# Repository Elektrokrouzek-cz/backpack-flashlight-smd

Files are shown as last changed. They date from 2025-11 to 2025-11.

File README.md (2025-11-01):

# Backpack flashlight - SMD
This is the construction of backpack flashlight with SMD components. It is based on ATTINY24A microcontroller.

PCB is 2-layer and was designed using KiCad 9. Fabrication output for JLCPCB is in gerber folder.

Happy soldering!

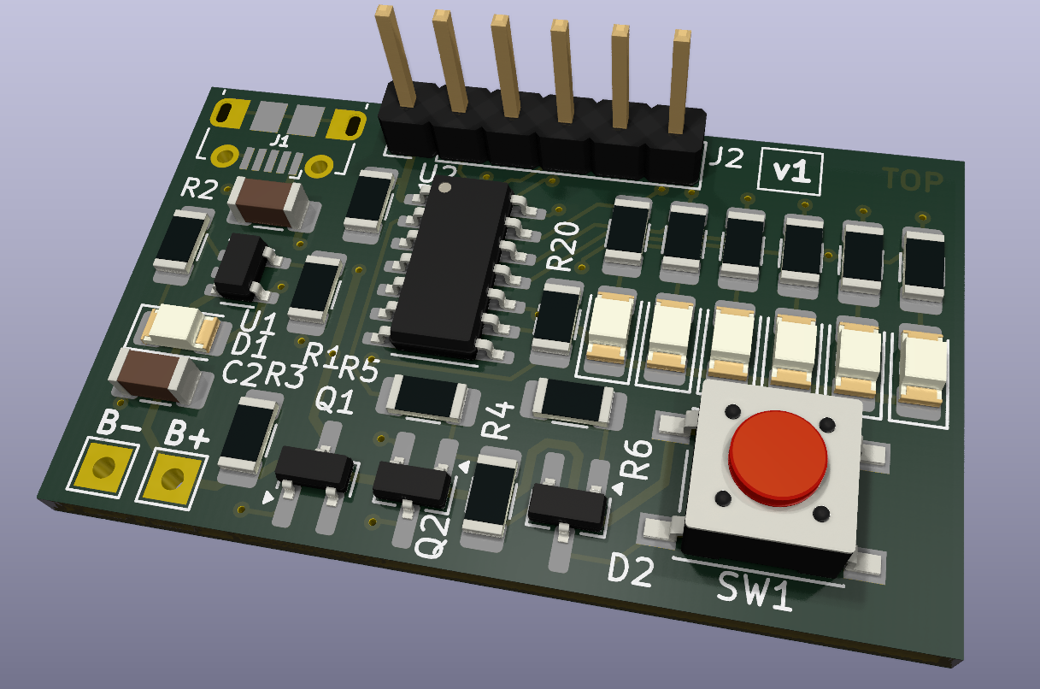
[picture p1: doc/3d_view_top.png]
3D view - top

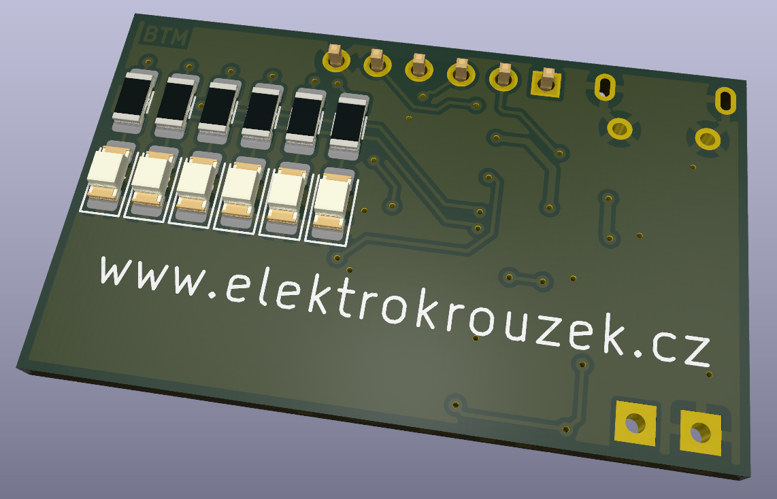
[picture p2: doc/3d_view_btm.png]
3D view - bottom

Flashlight

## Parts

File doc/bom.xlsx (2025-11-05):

Reference | Value | Qty
C1,C2 | 4u7 | 2
D1 | 1206 Red low intensity | 1
D3,D4,D5,D6,D7,D8,D9,D10,D11,D12,D13,D14 | 1206 Red high intensity | 12
D2 | BAS70-06 | 1
J1 | 105017-0001 | 1
J2 | 6pin | 1
Q1 | BSS84 | 1
Q2 | BC848 | 1
R1 | 47k | 1
R2 | 470R | 1
R3 | 2M2 | 1
R4,R5,R6,R19,R20 | 10k | 5
R7,R8,R9,R10,R11,R12,R13,R14,R15,R16,R17,R18 | 220R | 12
SW1 | 6x6 SMD | 1
TP1 | BAT+ | 1
TP2 | BAT- | 1
U1 | MCP73831-2-OT | 1
U2 | ATtiny24-20SS | 1

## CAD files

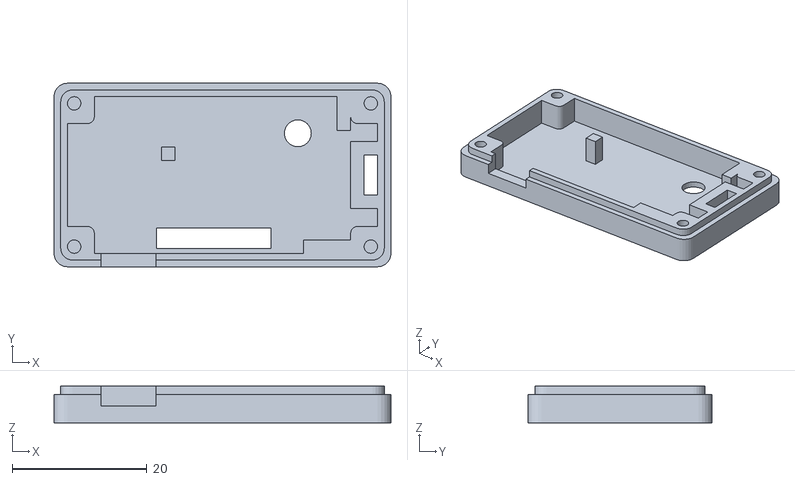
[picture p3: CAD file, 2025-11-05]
3d/Flashlight-top-hole.stl
50.1 x 27.3 x 5.50

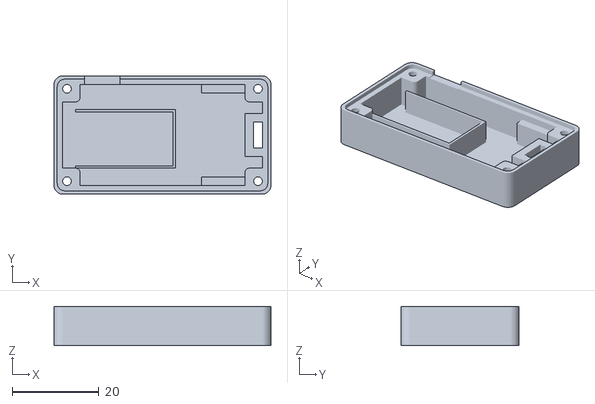
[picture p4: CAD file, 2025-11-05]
3d/Flashlight-bottom.stl
50.1 x 27.3 x 9.10

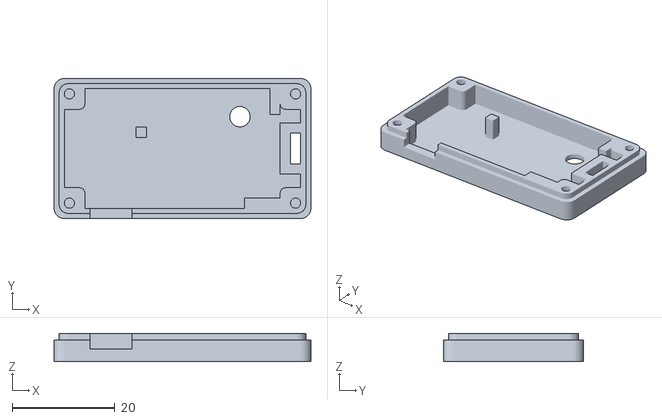
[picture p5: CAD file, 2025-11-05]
3d/Flashlight-top-no-hole.stl
50.1 x 27.3 x 5.50

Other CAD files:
3d/Flashlight-bottom.obj
3d/Flashlight-top-hole.obj
3d/Flashlight-top-no-hole.obj
3d/Flashlight.f3d

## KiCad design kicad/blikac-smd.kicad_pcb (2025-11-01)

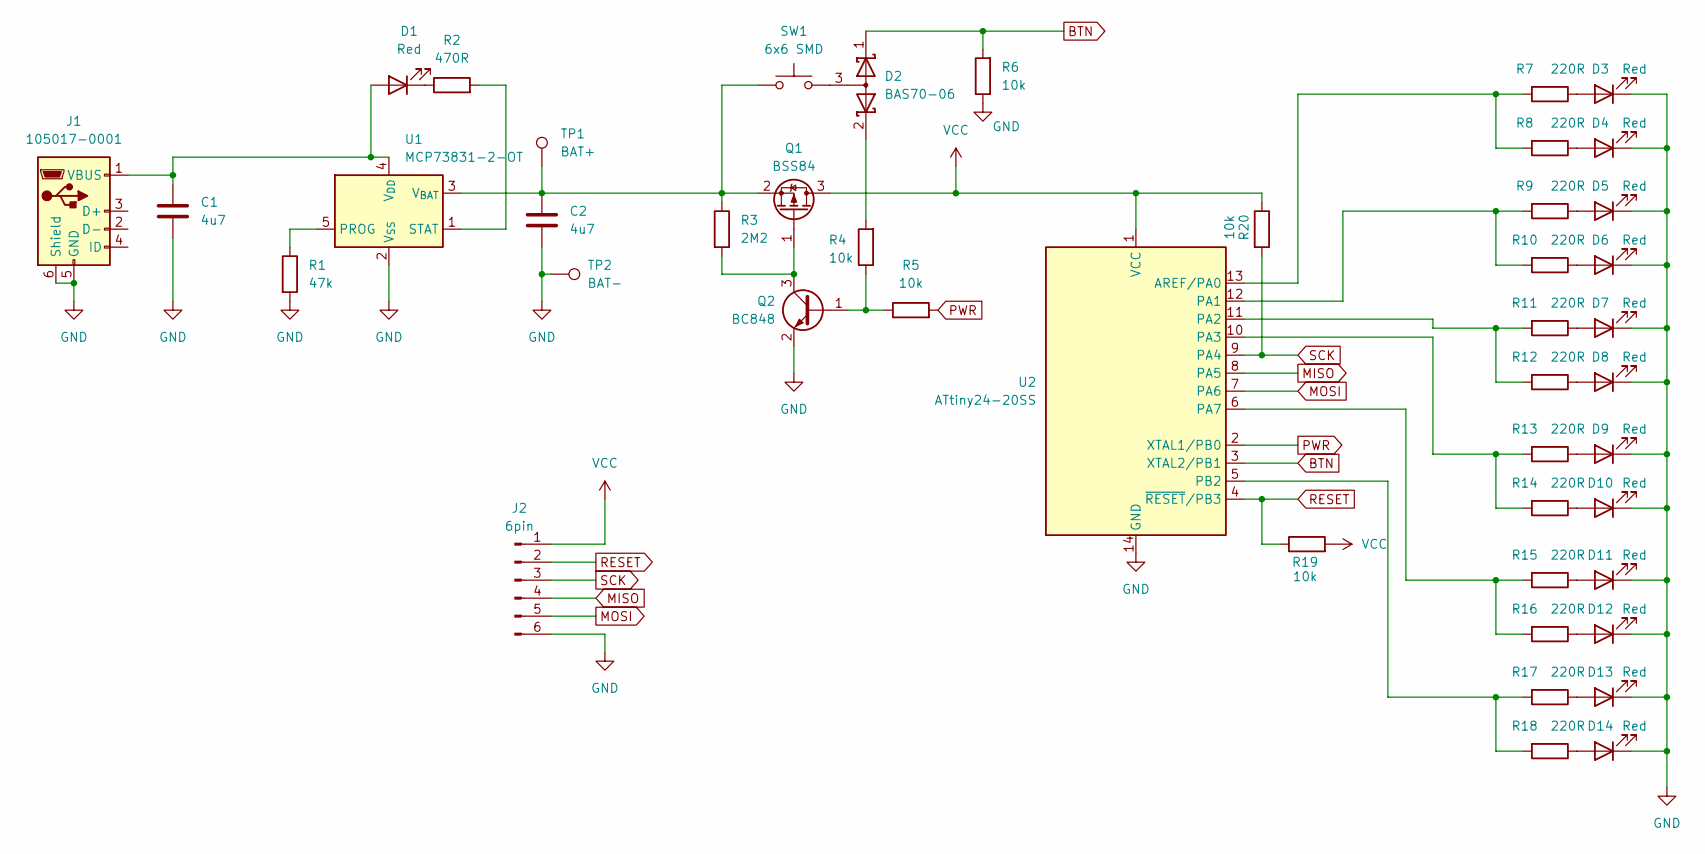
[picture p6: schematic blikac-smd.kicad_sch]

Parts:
C1, C2: 4u7; C_1206_3216Metric_Pad1.33x1.80mm_HandSolder
D1, D3, D4, D5, D6, D7, D8, D9, D10, D11, D12, D13, D14: Red; LED_1206_3216Metric_Pad1.42x1.75mm_HandSolder
D2: BAS70-06; SOT-23_Handsoldering
J1: 105017-0001; USB_Micro-B_Molex-105017-0001
J2: 6pin; PinHeader_1x06_P2.54mm_Vertical
Q1: BSS84; SOT-23_Handsoldering
Q2: BC848; SOT-23_Handsoldering
R1: 47k; R_1206_3216Metric_Pad1.30x1.75mm_HandSolder
R2: 470R; R_1206_3216Metric_Pad1.30x1.75mm_HandSolder
R3: 2M2; R_1206_3216Metric_Pad1.30x1.75mm_HandSolder
R4, R5, R6, R19, R20: 10k; R_1206_3216Metric_Pad1.30x1.75mm_HandSolder
R7, R8, R9, R10, R11, R12, R13, R14, R15, R16, R17, R18: 220R; R_1206_3216Metric_Pad1.30x1.75mm_HandSolder
SW1: 6x6 SMD; SW_SPST_PTS645
TP1: BAT+; TestPoint_THTPad_2.0x2.0mm_Drill1.0mm
TP2: BAT-; TestPoint_THTPad_2.0x2.0mm_Drill1.0mm
U1: MCP73831-2-OT; SOT-23-5
U2: ATtiny24-20SS; SOIC-14_3.9x8.7mm_P1.27mm

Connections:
BTN: D2.1 (K), R6.2, U2.3 (XTAL2/PB1)
GND: C1.2, C2.2, D3.1 (K), D4.1 (K), D5.1 (K), D6.1 (K), D7.1 (K), D8.1 (K), D9.1 (K), D10.1 (K), D11.1 (K), D12.1 (K), D13.1 (K), D14.1 (K), J1.5 (GND), J1.6 (Shield), J2.6, Q2.2 (E), R1.2, R6.1, TP2.1, U1.2 (V_{SS}), U2.14 (GND)
MISO: J2.4, U2.8 (PA5)
MOSI: J2.5, U2.7 (PA6)
unnamed: C1.1, D1.2 (A), J1.1 (VBUS), U1.4 (V_{DD})
unnamed: D1.1 (K), R2.1
unnamed: D2.3 (A), SW1.2
unnamed: D2.2 (K), R4.2
unnamed: D3.2 (A), R7.1
unnamed: D4.2 (A), R8.1
unnamed: D5.2 (A), R9.1
unnamed: D6.2 (A), R10.1
unnamed: D7.2 (A), R11.1
unnamed: D8.2 (A), R12.1
unnamed: D9.2 (A), R13.1
unnamed: D10.2 (A), R14.1
unnamed: D11.2 (A), R15.1
unnamed: D12.2 (A), R16.1
unnamed: D13.2 (A), R17.1
unnamed: D14.2 (A), R18.1
unnamed: Q1.1 (G), Q2.3 (C), R3.2
unnamed: C2.1, Q1.2 (S), R3.1, SW1.1, TP1.1, U1.3 (V_{BAT})
unnamed: Q2.1 (B), R4.1, R5.1
unnamed: R1.1, U1.5 (PROG)
unnamed: R2.2, U1.1 (STAT)
unnamed: R7.2, R8.2, U2.13 (AREF/PA0)
unnamed: R9.2, R10.2, U2.12 (PA1)
unnamed: R11.2, R12.2, U2.11 (PA2)
unnamed: R13.2, R14.2, U2.10 (PA3)
unnamed: R15.2, R16.2, U2.6 (PA7)
unnamed: R17.2, R18.2, U2.5 (PB2)
PWR: R5.2, U2.2 (XTAL1/PB0)
RESET: J2.2, R19.1, U2.4 (~RESET/PB3)
SCK: J2.3, R20.2, U2.9 (PA4)
VCC: J2.1, Q1.3 (D), R19.2, R20.1, U2.1 (VCC)

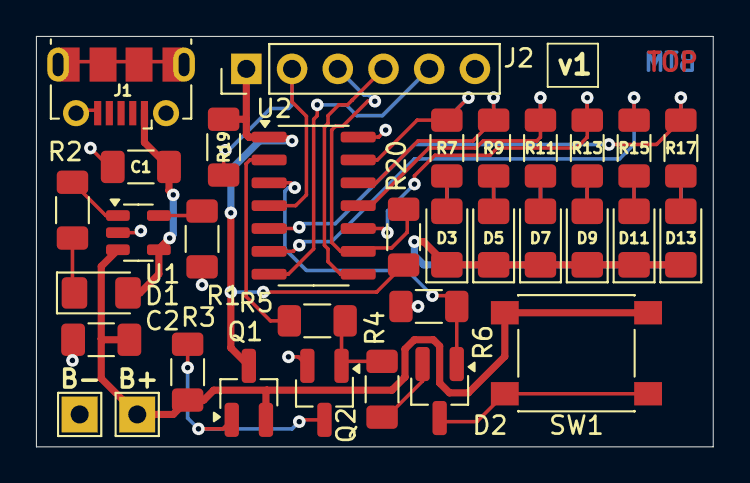
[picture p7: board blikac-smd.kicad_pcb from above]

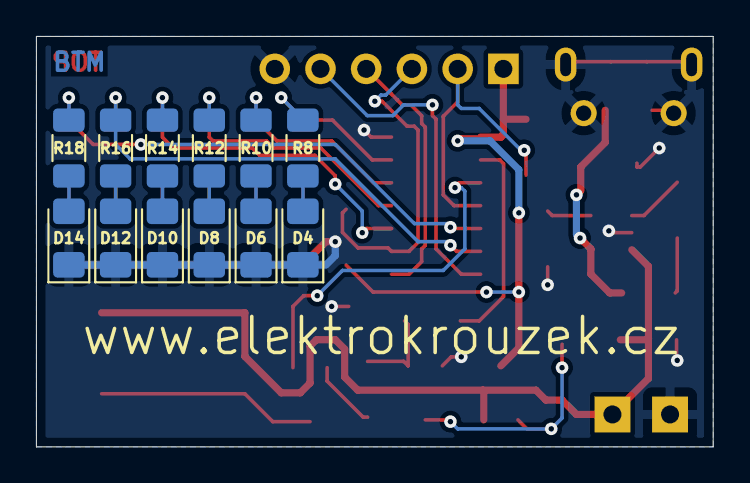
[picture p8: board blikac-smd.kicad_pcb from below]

Board: 2 copper layers, 37.6 x 22.8 mm, 45 parts (12 on the bottom side), 35 nets.

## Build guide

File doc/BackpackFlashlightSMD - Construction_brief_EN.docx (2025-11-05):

# Backpack Flashlight SMD

## Bill of materials

Annotation | Value | Qty
C1,C2 | 4u7 | 2
D1 | 1206 Red low intensity | 1
D3,D4,D5,D6,D7,D8,D9,D10,D11,D12,D13,D14 | 1206 Red high intensity | 12
D2 | BAS70-06 | 1
J1 | 105017-0001 | 1
J2 | 6pin | 1
Q1 | BSS84 | 1
Q2 | BC848 | 1
R1 | 47k | 1
R2 | 470R | 1
R3 | 2M2 | 1
R4,R5,R6,R19,R20 | 10k | 5
R7,R8,R9,R10,R11,R12,R13,R14,R15,R16,R17,R18 | 220R | 12
SW1 | 6x6 SMD | 1
TP1 | BAT+ | 1
TP2 | BAT- | 1
U1 | MCP73831-2-OT | 1
U2 | ATtiny24-20SS | 1

## PCB assembly

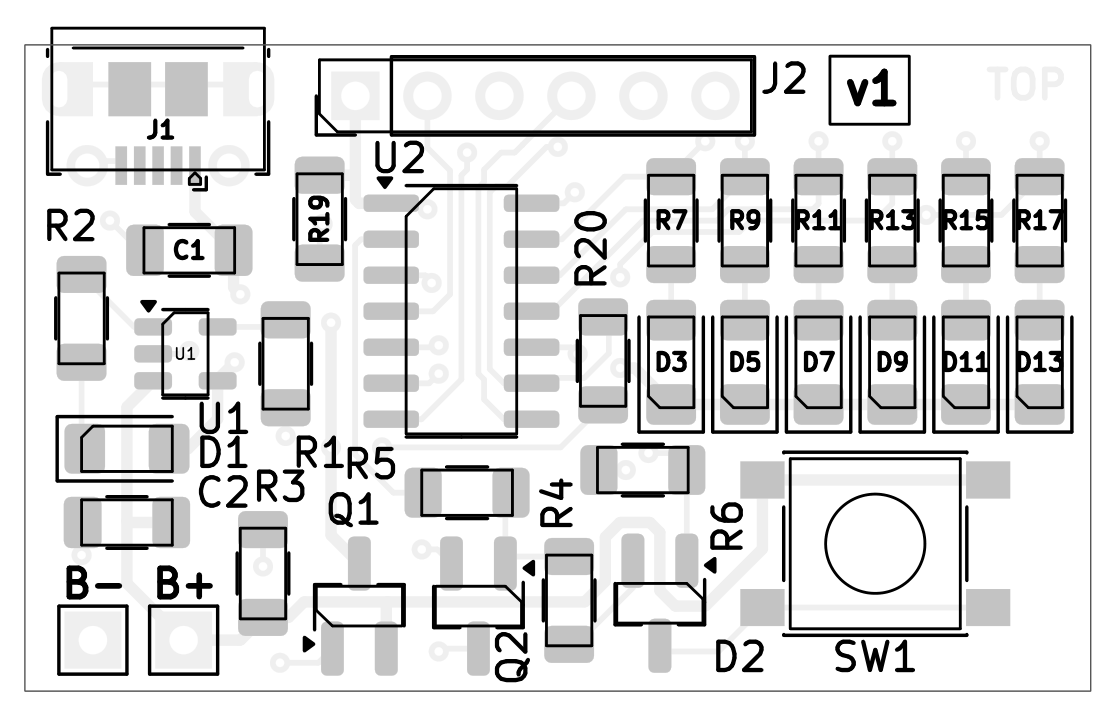
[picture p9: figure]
Obsah obrázku text, diagram, Plán, snímek obrazovky Obsah generovaný pomocí AI může být nesprávný.
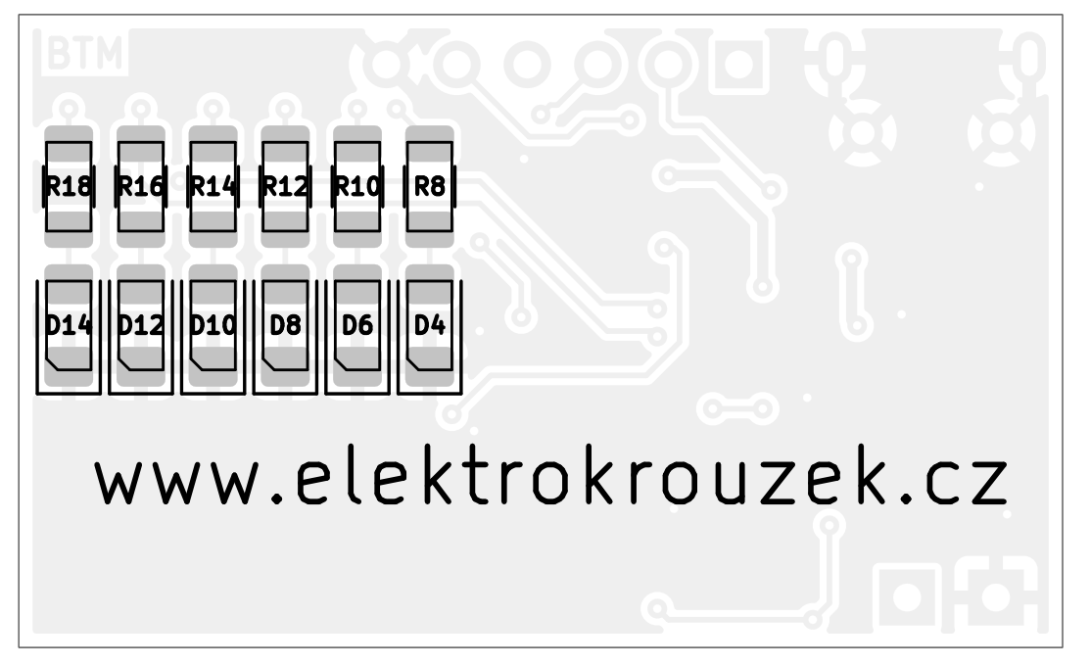
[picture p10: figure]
Obsah obrázku text, snímek obrazovky, Písmo, číslo Obsah generovaný pomocí AI může být nesprávný.

## Schematic

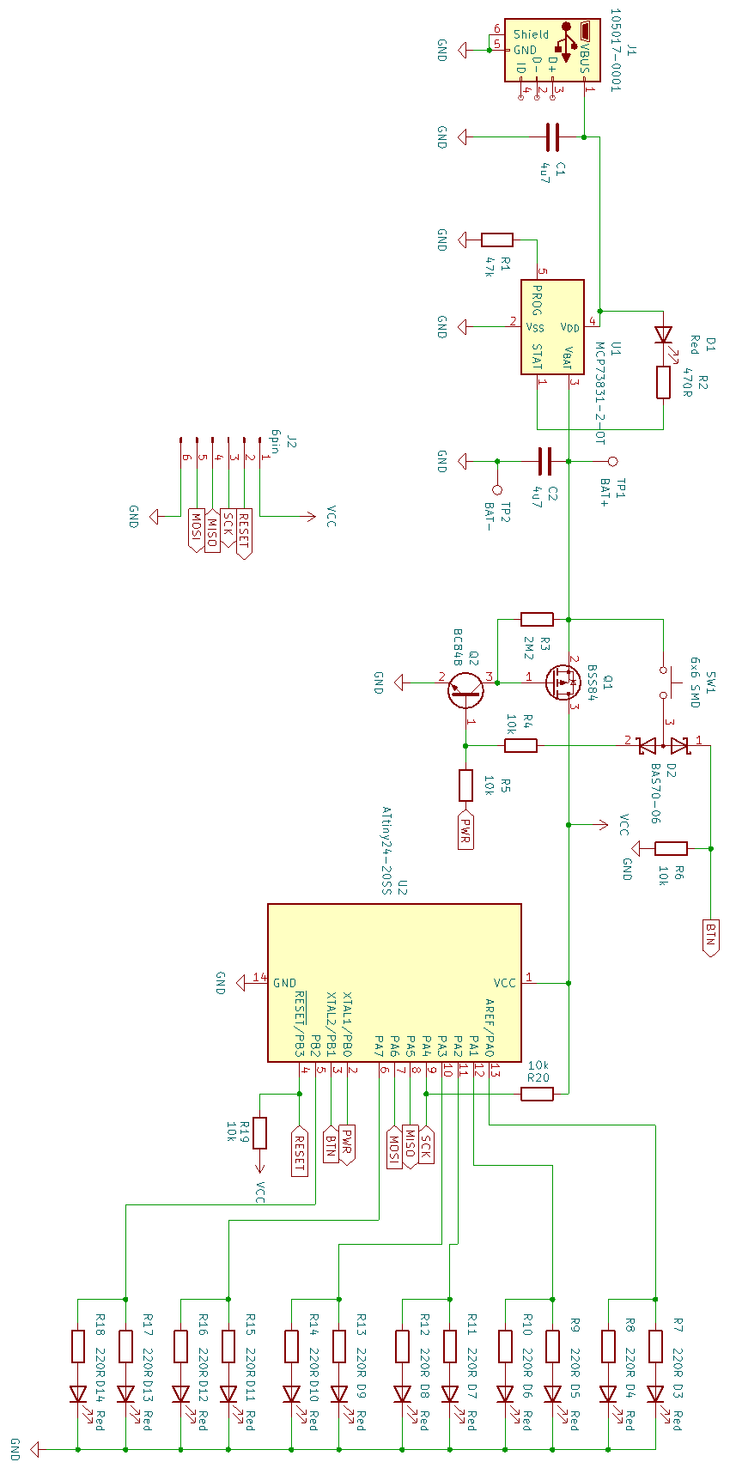
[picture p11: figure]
Obsah obrázku text, diagram, Plán Obsah generovaný pomocí AI může být nesprávný.

www.elektrokrouzek.cz

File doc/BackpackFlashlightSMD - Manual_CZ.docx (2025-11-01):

# Blikač na batoh SMD

## Popis zapojení

Konstrukce blikače na batoh založená na SMD komponentech.

Konstrukce je založena na mikrokontroleru ATTINY24A. Je napájena malým LiPol akumulátorem s nabíjecím obvodem. Obvod je zapnut držením tlačítka nejméně 2 sekundy. The circuit is turned on by holding a button for at least 2 seconds. Tranzistory Q2 a Q1 se otevřou ve chvíli stlačení tlačítka a dodávají napájecí napětí mikrokontroleru. Mikrokontroler následně aktivuje signál PWR, aby přidržel tranzistory otevřené i po uvolnění tlačítka. Stav tlačítka je signalizován signálem BTN, který je izolovaný od signálu PWR schottkyho diodou D2.

## Popis sestavení

Součástky jsou osazeny z obou stran plošného spoje. Začneme osazováním USB konektoru, rezistorů, kondenzátorů, diody D2, tranzistorů, mikrokontroleru a LED diod. Nakonec osadíme integrované obvody, tlačítko a připojíme akumulátor.

Poznámka: LED diody jsou v 1206 SMD pouzdru. Lze použít jakýkoliv typ. Nejlepší jsou LED diody s malým vyzařovacím úhlem.

## Oživení

Pokud jste pracovali pečlivě mělo by zapojení fungovat na první pokus, pokud je mikrokontroler naprogramován.

## Seznam součástek

Označení | Hodnota | Počet
C1,C2 | 4u7 | 2
D1,D3,D4,D5,D6,D7,D8,D9,D10,D11,D12,D13,D14 | 1206 Red | 13
D2 | BAS70-06 | 1
J1 | 105017-0001 | 1
J2 | 6pin | 1
Q1 | BSS84 | 1
Q2 | BC848 | 1
R1 | 47k | 1
R2 | 470R | 1
R3 | 2M2 | 1
R4,R5,R6,R19,R20 | 10k | 5
R7,R8,R9,R10,R11,R12,R13,R14,R15,R16,R17,R18 | 220R | 12
SW1 | 6x6 SMD | 1
TP1 | BAT+ | 1
TP2 | BAT- | 1
U1 | MCP73831-2-OT | 1
U2 | ATtiny24-20SS | 1

## Osazovací výkresy

Obsah obrázku text, diagram, Plán, snímek obrazovky Obsah generovaný pomocí AI může být nesprávný.
Obsah obrázku text, snímek obrazovky, Písmo, číslo Obsah generovaný pomocí AI může být nesprávný.

## Programování mikrokontroleru

K naprogramování mikrokontroleru lze použít nejrůznější programátory pro Atmer AVR. My jsme použili programátor Asix Presto. Následující obrázek znázorňuje propojení programátoru s konektorem J2 (čísla pinů konektoru J2 jsou červeně).

Zdrojový kód a binární soubor je ke stažení na githubu kroužku:

https://github.com/Elektrokrouzek-cz/backpack-flashlight-smd

## Schéma

Obsah obrázku text, diagram, Plán Obsah generovaný pomocí AI může být nesprávný.

www.elektrokrouzek.cz

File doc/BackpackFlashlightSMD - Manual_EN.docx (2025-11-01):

# Backpack Flashlight SMD

## Schematic description

This is a construction of backpack flashlight based on SMD components.

The whole construction is based on ATTINY24 microcontroller. It is powered by tiny LiPol accumulator with charging circuit. The circuit is turned on by holding a button for at least 2 seconds. Q2 and Q1 transistors are turned on when button is pressed sourcing microcontroller with power. Microcontroller then activates PWR signal to keep transistors turned on. Button state is signalized by BTN signal that is isolated from the PWR signal by dual Schottky diode D2.

## Construction

Construction has components placed on both sides of the PCB. We start populating USB connector, resistors, then continue with capacitors, diode D2, transistors and LEDs. Finally, we populated ICs and button.

Note: LED diodes are in 1206 SMD package. You can use any type. The best are LED diodes with low emitting angle.

## How to get it into service

It should work on the first try when everything is soldered well and microcontroller is programmed.

## Bill of materials

Annotation | Value | Qty
C1,C2 | 4u7 | 2
D1,D3,D4,D5,D6,D7,D8,D9,D10,D11,D12,D13,D14 | 1206 Red | 13
D2 | BAS70-06 | 1
J1 | 105017-0001 | 1
J2 | 6pin | 1
Q1 | BSS84 | 1
Q2 | BC848 | 1
R1 | 47k | 1
R2 | 470R | 1
R3 | 2M2 | 1
R4,R5,R6,R19,R20 | 10k | 5
R7,R8,R9,R10,R11,R12,R13,R14,R15,R16,R17,R18 | 220R | 12
SW1 | 6x6 SMD | 1
TP1 | BAT+ | 1
TP2 | BAT- | 1
U1 | MCP73831-2-OT | 1
U2 | ATtiny24-20SS | 1

## PCB assembly

Obsah obrázku text, diagram, Plán, snímek obrazovky Obsah generovaný pomocí AI může být nesprávný.
Obsah obrázku text, snímek obrazovky, Písmo, číslo Obsah generovaný pomocí AI může být nesprávný.

## Microcontroller programming

Several programmers for Atmel AVR can be used for microcontroller programming. We’ve used Asix Presto. Following picture shows connection of Asix Presto to J2 connector (J2 pin numbers are red).

Source code and binary file can be downloaded from club github:

https://github.com/Elektrokrouzek-cz/backpack-flashlight-smd

## Schematic

Obsah obrázku text, diagram, Plán Obsah generovaný pomocí AI může být nesprávný.

www.elektrokrouzek.cz

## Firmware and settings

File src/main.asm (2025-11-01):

start:
	ldi r16,low(RAMEND)			// Init stack pointer
	out SPL,r16
power_on_wait_button:
	ldi r16, 5					// Wait 50ms
	rcall sleep_10ms
	in r16, PINB
	andi r16, 0x02				// Check if button is still pressed
	breq power_on_wait_button
	inc r17						// Increment counter
	cpi r17, 40					// Holding button for 2 seconds?
	brge power_on				// Yes -> turn on
	rjmp power_on_wait_button
power_on:
	ldi r16, 0x05				// Init PORTB (outputs)
	out DDRB, r16
	ldi r16, 0x01				// Power on (turn on transistor)
	out PORTB, r16
	ldi r16, 0x8f				// Init PORTA (outputs)
	out DDRA, r16
	ldi r16, 0x0
	out PORTA, r16

	ldi r17, 0					// Selected program
	ldi r18, 0					// LED content
	ldi r19, 0					// Program step
	ldi r20, 0					// Button hold counter
	ldi r21, 0					// Wait for button release
loop:
	in r16, PINB
	andi r16, 0x02				// Check if button is pressed
	brne loop_inc_button		
	clr r20						// Button not pressed - reset timers
	clr r21
	rjmp loop_skip_button
loop_inc_button:
	inc r20						// Button pressed - increment hold timer
	cpi r20, 40					// Check if it is held for 2 seconds
	brlo loop_check_prog_change // No -> check for program change
	rjmp power_off				// Turn off
loop_check_prog_change:
	cpi r20, 2					// Check if held for 100ms
	brlo loop_skip_button		// No -> skip
	cpi r21, 1					// Wait for button release
	breq loop_skip_button		// Button not released -> skip
	ldi r21, 1					// Set "wait for button release" flag
	inc r17						// Increment program
	cpi r17, 6					// Check maximal program count
	brne loop_skip_button
	clr r17						// Set program 0

loop_skip_button:
	cpi r17, 0					// Program 0?
	brne loop_1
	rcall prog_1
loop_1:
	cpi r17, 1					// Program 1?
	brne loop_2
	rcall prog_2
loop_2:
	cpi r17, 2					// Program 2?
	brne loop_3
	rcall prog_3
loop_3:
	cpi r17, 3					// Program 3?
	brne loop_4
	rcall prog_4
loop_4:
	cpi r17, 4					// Program 4?
	brne loop_5
	rcall prog_5
loop_5:
	cpi r17, 5					// Program 5?
	brne loop_6
	rcall prog_6
loop_6:
	mov r16, r18				// Show LEDs
	rcall show
	ldi r16, 5					// Wait 50ms
	rcall sleep_10ms
	rjmp loop					// And again!

power_off:
	ldi r16, 0x21				// Display turn off LED sequence
	rcall show
	ldi r16, 50
	rcall sleep_10ms
	ldi r16, 0x12
	rcall show
	ldi r16, 50
	rcall sleep_10ms
	ldi r16, 0x0c
	rcall show
	ldi r16, 50
	rcall sleep_10ms
	ldi r16, 0x0
	rcall show
	ldi r16, 50
	rcall sleep_10ms
	clr r17
power_off_wait_button:
	ldi r16, 5					// Wait 50ms
	rcall sleep_10ms
	in r16, PINB
	andi r16, 0x02				// Check button release
	brne power_off_wait_button_reset // No -> reset counter
	inc r17
	cpi r17, 4					// Button must be released for 40ms
	brlo power_off_wait_button
power_off_loop:
	ldi r16, 0					// Turn off
	out PORTB, r16
	rjmp power_off_loop
power_off_wait_button_reset:
	clr r17						// Reset counter
	rjmp power_off_wait_button  // And wait again

// Program 1 - blink all LEDs
prog_1:
	cpi r19, 0
	brne prog_1_1
	ldi r18, 0
	rjmp prog_1_inc
prog_1_1:
	cpi r19, 5
	brne prog_1_2
	ldi r18, 0x3f
	rjmp prog_1_inc
prog_1_2:
prog_1_inc:
	inc r19
	cpi r19, 7
	brlo prog_1_end
	clr r19
prog_1_end:
	ret

// Program 2 - blink left, blink right
prog_2:
	cpi r19, 0
	brne prog_2_1
	ldi r18, 0
	rjmp prog_2_inc
prog_2_1:
	cpi r19, 3
	brne prog_2_2
	ldi r18, 0x07
	rjmp prog_2_inc
prog_2_2:
	cpi r19, 4
	brne prog_2_3
	ldi r18, 0
	rjmp prog_2_inc
prog_2_3:
	cpi r19, 5
	brne prog_2_4
	ldi r18, 0x07
	rjmp prog_2_inc
prog_2_4:
	cpi r19, 6
	brne prog_2_5
	ldi r18, 0
	rjmp prog_2_inc
prog_2_5:
	cpi r19, 9
	brne prog_2_6
	ldi r18, 0x38
	rjmp prog_2_inc
prog_2_6:
	cpi r19, 10
	brne prog_2_7
	ldi r18, 0
	rjmp prog_2_inc
prog_2_7:
	cpi r19, 11
	brne prog_2_8
	ldi r18, 0x38
	rjmp prog_2_inc
prog_2_8:
prog_2_inc:
	inc r19
	cpi r19, 12
	brlo prog_2_end
	clr r19
prog_2_end:
	ret

// Program 3 - knight rider
prog_3:
	mov r16, r19
	cpi r19, 6
	brge prog_3_1
	ldi r18, 1
prog_3_lsl:
	cpi r16, 0
	breq prog_3_inc
	lsl r18
	dec r16
	rjmp prog_3_lsl
prog_3_1:
	ldi r18, 0x20
	subi r16, 6
prog_3_lsr:
	cpi r16, 0
	breq prog_3_inc
	lsr r18
	dec r16
	rjmp prog_3_lsr
prog_3_2:
prog_3_inc:
	inc r19
	cpi r19, 12
	brlo prog_3_end
	clr r19
prog_3_end:
	ret

// Program 4 - blink center, blink outer
prog_4:
	cpi r19, 0
	brne prog_4_1
	ldi r18, 0
	rjmp prog_4_inc
prog_4_1:
	cpi r19, 3
	brne prog_4_2
	ldi r18, 0x0c
	rjmp prog_4_inc
prog_4_2:
	cpi r19, 4
	brne prog_4_3
	ldi r18, 0
	rjmp prog_4_inc
prog_4_3:
	cpi r19, 5
	brne prog_4_4
	ldi r18, 0x0c
	rjmp prog_4_inc
prog_4_4:
	cpi r19, 6
	brne prog_4_5
	ldi r18, 0
	rjmp prog_4_inc
prog_4_5:
	cpi r19, 9
	brne prog_4_6
	ldi r18, 0x33
	rjmp prog_4_inc
prog_4_6:
	cpi r19, 10
	brne prog_4_7
	ldi r18, 0
	rjmp prog_4_inc
prog_4_7:
	cpi r19, 11
	brne prog_4_8
	ldi r18, 0x33
	rjmp prog_4_inc
prog_4_8:
prog_4_inc:
	inc r19
	cpi r19, 12
	brlo prog_4_end
	clr r19
prog_4_end:
	ret

// Program 5 - blink left, center, right
prog_5:
	cpi r19, 0
	brne prog_5_1
	ldi r18, 0
	rjmp prog_5_inc
prog_5_1:
	cpi r19, 5
	brne prog_5_2
	ldi r18, 0x30
	rjmp prog_5_inc
prog_5_2:
	cpi r19, 7
	brne prog_5_3
	ldi r18, 0x00
	rjmp prog_5_inc
prog_5_3:
	cpi r19, 12
	brne prog_5_4
	ldi r18, 0x0c
	rjmp prog_5_inc
prog_5_4:
	cpi r19, 14
	brne prog_5_5
	ldi r18, 0x00
	rjmp prog_5_inc
prog_5_5:
	cpi r19, 19
	brne prog_5_6
	ldi r18, 0x03
	rjmp prog_5_inc
prog_5_6:
	cpi r19, 21
	brne prog_5_7
	ldi r18, 0x00
	rjmp prog_5_inc
prog_5_7:
	cpi r19, 26
	brne prog_5_8
	ldi r18, 0x0c
	rjmp prog_5_inc
prog_5_8:
prog_5_inc:
	inc r19
	cpi r19, 28
	brlo prog_5_end
	clr r19
prog_5_end:
	ret

// Program 6 - knight rider symetrical
prog_6:
	cpi r19, 0
	brne prog_6_1
	ldi r18, 0x21
	rjmp prog_6_inc
prog_6_1:
	cpi r19, 1
	brne prog_6_2
	ldi r18, 0x12
	rjmp prog_6_inc
prog_6_2:
	cpi r19, 2
	brne prog_6_3
	ldi r18, 0x0c
	rjmp prog_6_inc
prog_6_3:
	cpi r19, 3
	brne prog_6_4
	ldi r18, 0x12
	rjmp prog_6_inc
prog_6_4:
	cpi r19, 4
	brne prog_6_5
	ldi r18, 0x21
	rjmp prog_6_inc
prog_6_5:
prog_6_inc:
	inc r19
	cpi r19, 5
	brlo prog_6_end
	clr r19
prog_6_end:
	ret

// Show LED content (r16 as input, bits 0 to 5)
show:
	cbi PORTA, 0
	cbi PORTA, 1
	cbi PORTA, 2
	cbi PORTA, 3
	cbi PORTA, 7
	cbi PORTB, 2
	sbrc r16, 0
	sbi PORTA, 0
	sbrc r16, 1
	sbi PORTA, 1
	sbrc r16, 2
	sbi PORTA, 2
	sbrc r16, 2
	sbi PORTA, 2
	sbrc r16, 3
	sbi PORTA, 3
	sbrc r16, 4
	sbi PORTA, 7
	sbrc r16, 5
	sbi PORTB, 2
	ret

sleep_10ms:					// Wait N x 10ms (r16 is input - N)
	push r16
	push r17
	push r18
	clr r17
	ldi r18, 12
sleep_loop:
	dec r17
	brne sleep_loop
	dec r18
	brne sleep_loop
	ldi r18, 12
	dec r16
	brne sleep_loop
	pop r18
	pop r17
	pop r16
	ret

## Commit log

2025-11-05 Manual update, 3D models, construction brief
    [Flashlight-bottom.obj, Flashlight-bottom.stl, Flashlight-top-hole.obj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]
2025-11-05 BOM update
    [bom.xlsx]
